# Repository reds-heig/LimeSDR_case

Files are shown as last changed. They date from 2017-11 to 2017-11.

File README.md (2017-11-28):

# LimeSDR_case

Here you will find the LimeSDR case developed at the [REDS institute](https://reds.heig-vd.ch/). This case was designed using SolidWorks for 3D printing.

## BOM

The BOM contains a list of properly-sized heatsinks with order links, as well as adhesive foil, a 12VDC fan and SMA pigtails. You will have to acquire the screws by yourself.

## Mounting

After ordering all the parts, use the adhesive foil to mount the heatsinks on the corresponding chips. Use the *Remark* column in the BOM and the [PCB layout](https://github.com/myriadrf/LimeSDR-USB/blob/master/hardware/plug/1v4/Project%20Outputs%20for%20LimeSDR-USB_1v4_LMS031pad/LimeSDR-USB_1v4_PCB_Drawings.PDF) in order to know what goes where. The DC fan has to be soldered between J21 GND (black) and J21 VCC EXT (red). This way, it will be on whenever an external power supply is applied. The fan will work with 9VDC supplies as well, albeit at a lower speed.

## More information

A thermal analysis is available on [our blog](http://blog.reds.ch/?p=207).

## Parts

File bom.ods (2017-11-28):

Item | Brand | Mfr. Part No. | RS Stock No. | Qty | Link | Remark
Heatsink, BGA, 28.5K/W, 10 x 10 x 10mm, Adhesive Foil, Conductive Foil | Fischer Elektronik | ICK BGA 10x10x10 | 674-4747 | 2 | http://uk.rs-online.com/web/p/kuhlkorper/6744747/?sra=pstk | IC1 (LMS7002M), IC13 (Cypress FX3)
Heatsink, DIP, PLCC, 74K/W, 8 x 8 x 6mm | Fischer Elektronik | ICKSMDF8SA | 504-0738 | 1 | http://uk.rs-online.com/web/p/kuhlkorper/5040738/?sra=pstk | L2
Heatsink, DIP, PLCC, 71K/W, 10 x 8 x 6mm | Fischer Elektronik | ICKSMDF10 | 504-0744 | 2 | http://uk.rs-online.com/web/p/kuhlkorper/5040744/?sra=pstk | L1, IC35 (LP38503)
Heatsink, PGA, 14.8K/W, 23 x 23 x 12.3mm, Adhesive Foil, Conductive Foil | Fischer Elektronik | ICK PGA 8x8x12 | 674-4743 | 1 | http://uk.rs-online.com/web/p/kuhlkorper/6744743/?sra=pstk | IC8 (Altera Cyclone IV)
DC Axial Fan, 45 x 45 x 10mm, 15.6m³/h, 1.26W, 12 V dc (MB Series) | Sunon | MB45101V2-000U-A99 | 758-8229 | 1 | http://uk.rs-online.com/web/p/axiallufter/7588229/?sra=pstk | Solder between J21 GND and J21 VCC EXT
Heatsink Adhesive Tape for use with Heatsink | Bergquist | BP100-0.005-00-00-12 | 477-4856 | 1 | http://uk.rs-online.com/web/p/kuhlkorper-montagezubehor/4774856/?sra=pstk
100mm Audio Video Mixed Cable Assembly UFL to Female SMA | RF Solutions | CBA-UFLSMA | 761-9881 | 12 | http://uk.rs-online.com/web/p/a-v-mixed-cable-assemblies/7619881/
Mounting instructions
4 x screw steel M3 10mm
4 x standoff nylon M3 25mm female-female (between cover and board)
4 x standoff nylon M3 10mm female-male (below board)
4 x standoff steel M3 10mm female-male (below case)
4 x bolts steel M3 25mm (for the fan)
4 x nuts steel M3 (for the fan)
DC fan wires to be soldered to J21’s GND & VCC EXT.

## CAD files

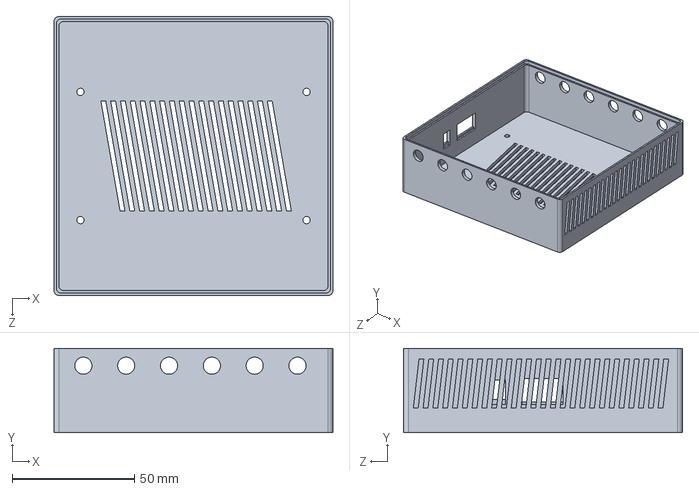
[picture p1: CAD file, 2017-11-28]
bottom/lime_sdr_part_bottom.STEP
114.0 x 34.5 x 114.0 mm

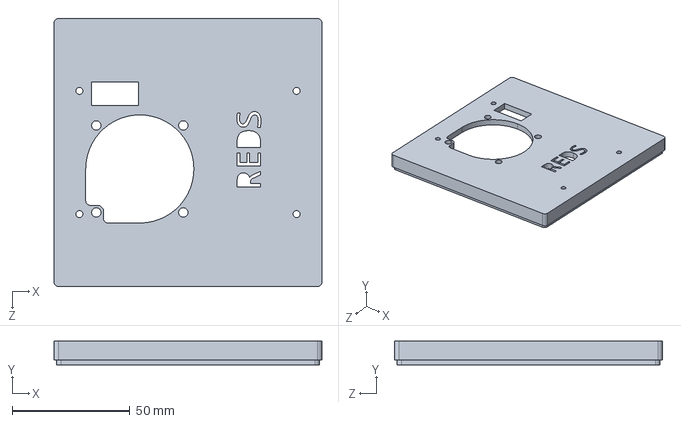
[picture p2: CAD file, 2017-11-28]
top/lime_sdr_part_top.STEP
114.0 x 10.0 x 114.0 mm

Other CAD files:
bottom/lime_sdr_part_bottom.SLDPRT
bottom/lime_sdr_part_bottom.STL
top/lime_sdr_part_top.SLDPRT
top/lime_sdr_part_top.STL

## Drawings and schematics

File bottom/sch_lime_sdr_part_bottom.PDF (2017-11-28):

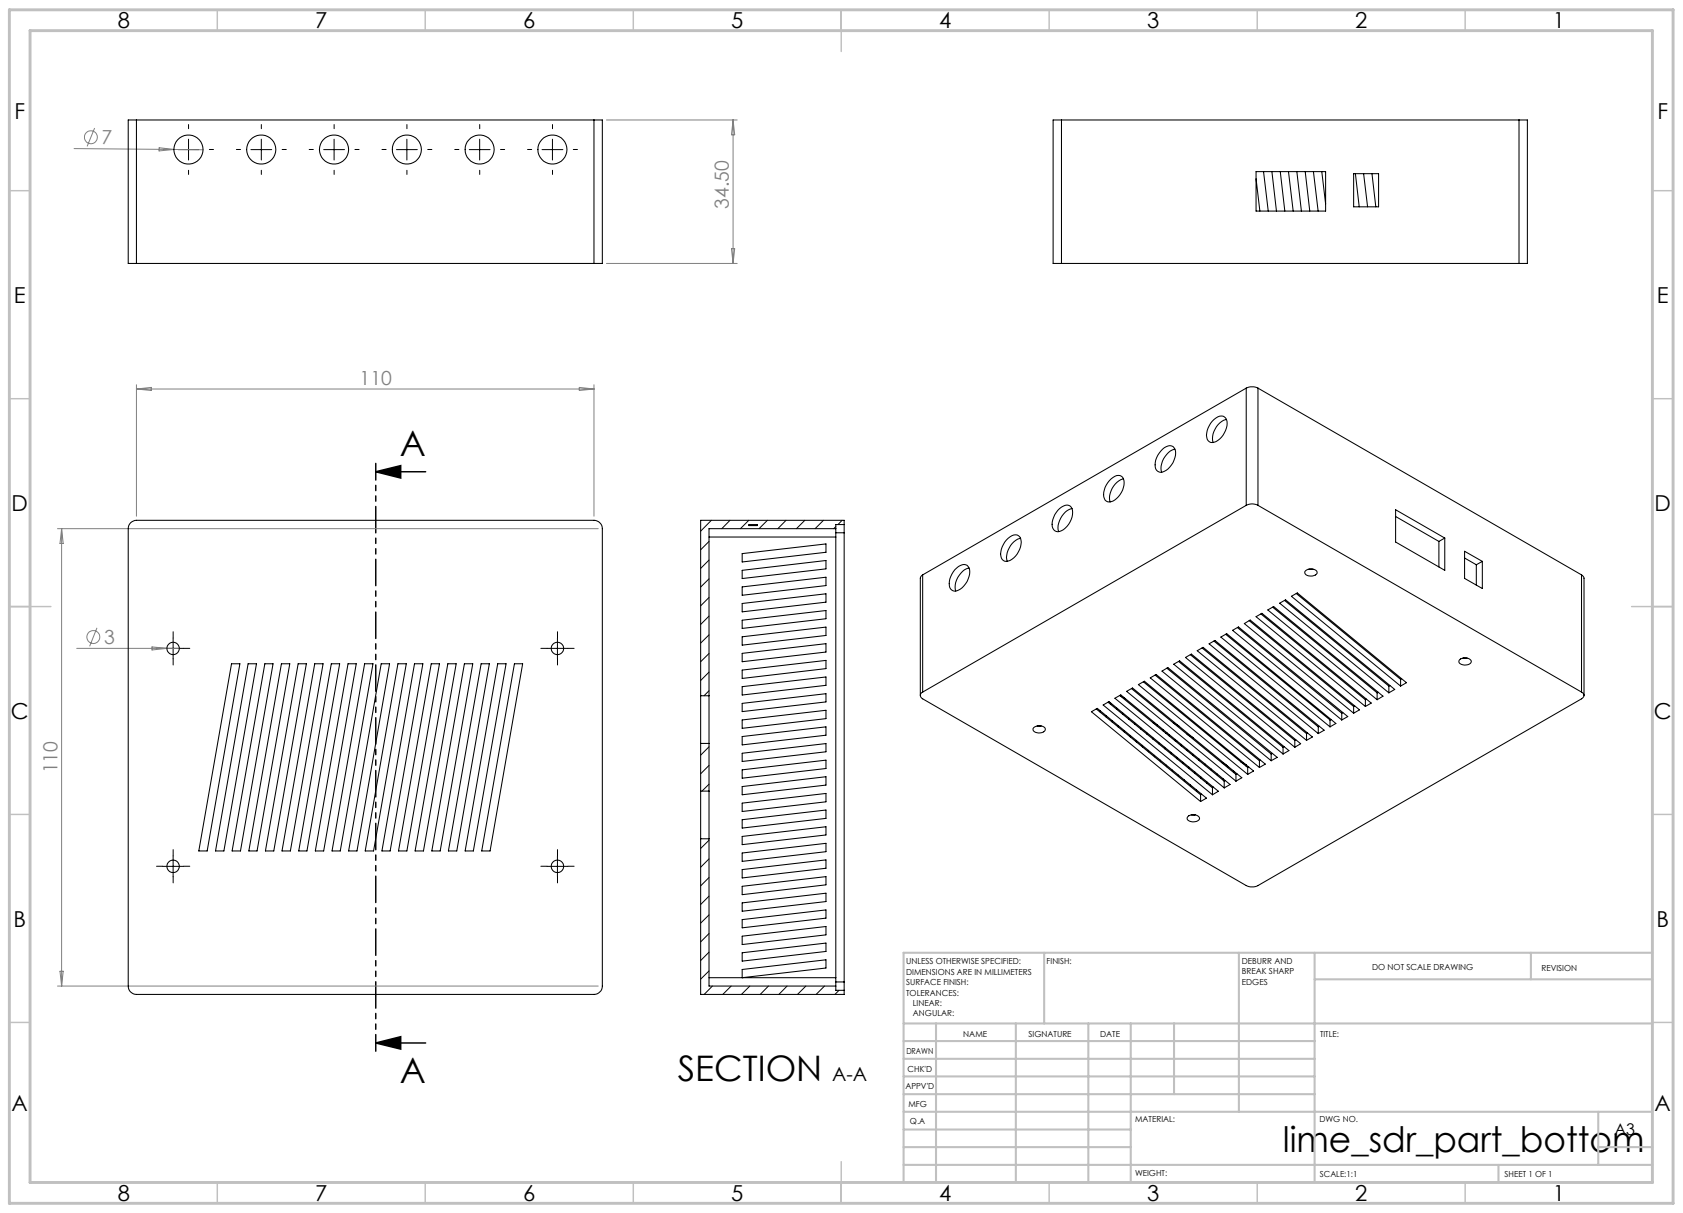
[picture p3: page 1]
SECTION A-A; FINISH:; DEBURR AND; BREAK SHARP; DO NOT SCALE DRAWING; REVISION; SCALE:1:1; SHEET 1 OF 1

UNLESS OTHERWISE SPECIFIED:
DIMENSIONS ARE IN MILLIMETERS
SURFACE FINISH:
TOLERANCES:
LINEAR:
ANGULAR:

NAME | SIGNATURE | DATE | | | | TITLE:

DRAWN
CHK'D
APPV'D
MFG
Q.A | | | | MATERIAL: lime_sdr_part_bottom | DWG NO. | A3

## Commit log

2017-11-28 3d: adding files
    [lime_sdr_part_bottom.SLDPRT, lime_sdr_part_bottom.STEP, lime_sdr_part_bottom.STL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]
2017-11-28 bom: adding
    [bom.ods]
